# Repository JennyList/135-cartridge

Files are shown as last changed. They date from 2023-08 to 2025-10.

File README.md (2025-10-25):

# A Re-usable 35mm Film Cartridge
A 3D-printable re-usable film cartridge for 135 cameras.

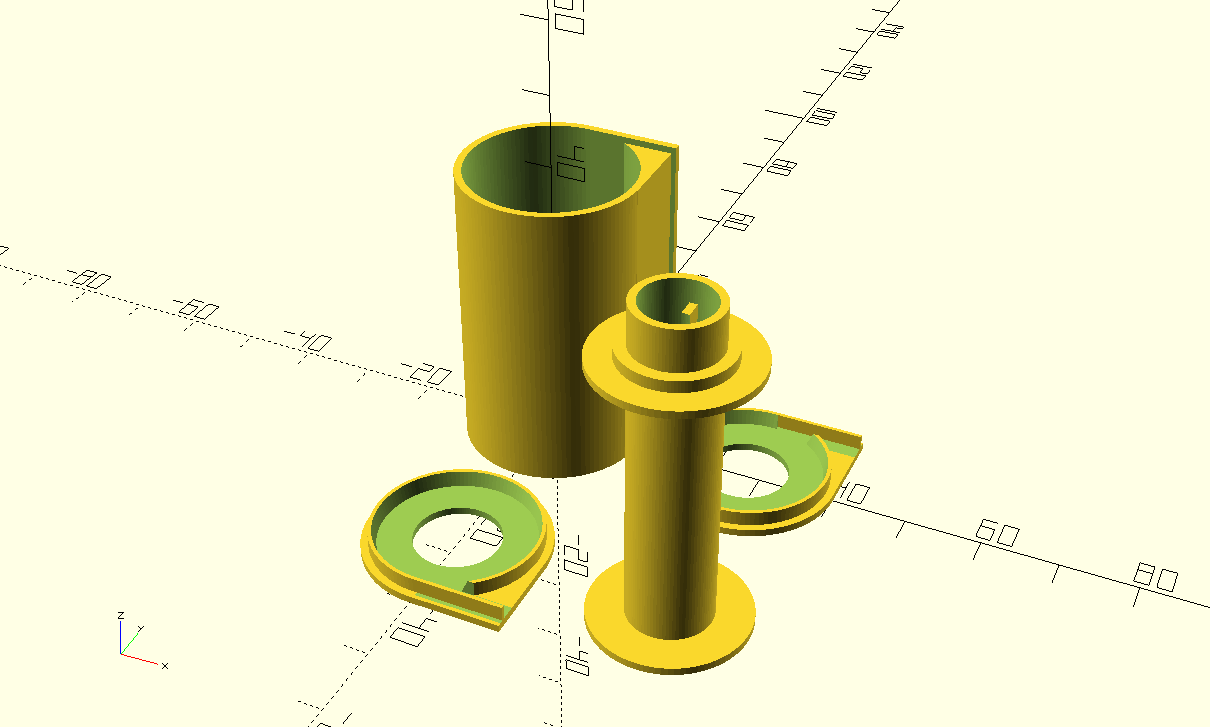
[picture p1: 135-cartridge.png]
A render of the STL for the cartridge


The cartridge, spool, and lids should be printed, then a set of two felt light seals should be glued along the opposite sides of the cartridge film opening. I used the soft side of a piece of black velcro, but a strip of black felt can also be used. Use a knife blade to keep the two felt pieces from sticking to each other. Once the glue has set, the felt can be trimmed at each end.

Once you've attached the felt, glue one end piece in place. Attach the film strip to the reel with a piece of tape, slide it into the cartridge with the film between the pieces of felt. Then place the other end piece on the cartridge and secure it with a piece of masking tape. You can then wind the film into the cartridge.

Take care for light leaks, suggest loading in a darkroom and avoiding strong light when loading your camera.

## Licence

This model is licensed under the [Creative Commons Attribution Share Alike 4.0 International licence](license.md).



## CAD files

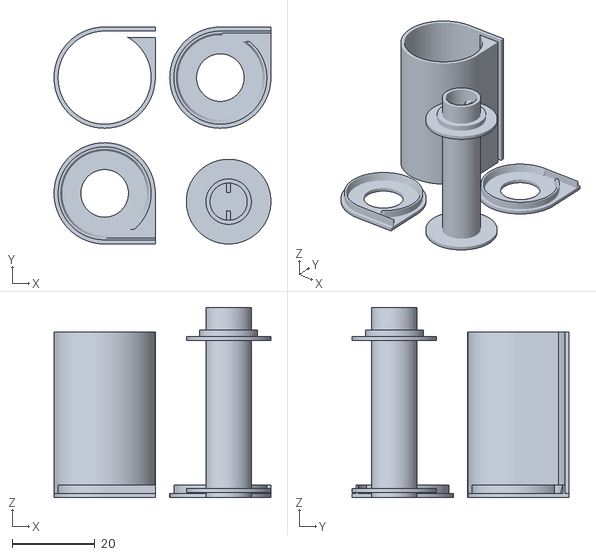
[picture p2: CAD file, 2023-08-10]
135-cartridge.stl
52.5 x 52.5 x 46.0

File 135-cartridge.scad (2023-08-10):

/*
A re-usable 135 film cartridge
Jenny List 2023
CC-BY-SA 4.0

*/
module Reel35(){
    difference(){
        union(){
            cylinder(46,5.5,5.5,$fn=90,true); //shaft
            translate([0,0,16.75]) cylinder(1.5,7,7,$fn=120,true); //spacer
            translate([0,0,-21.25]) cylinder(1,10.25,10.25,$fn=90,true); //bottom flange
            translate([0,0,15.5]) cylinder(1,10.25,10.25,$fn=90,true);//top flange
        } 
        translate([0,0,-15.5])cylinder(15,4.5,4.5,$fn=90,true); //cut out bottom 
        translate([0,0,15.5])cylinder(15,4.5,4.5,$fn=90,true); //cut out top
    }
    difference(){ //tabs for film winder to engage
        cube([1,10,40],true); 
        cylinder(40,2.25,2.25,$fn=90,true);
    }
}

module Lid35(){
    difference(){
        union(){
            cylinder(1,12.25,12.25,$fn=120,true); //flat lid
            translate([11.75,5.75,0])cube([1,13,1],true); //tangent
            translate([6,11.75,0])cube([12,1,1],true); //tangent.
            translate([5.5,5,0]) cube([13,13,1],true); //Cube to fill in the hole
            translate([0,0,1.5]) cylinder(2,11.25,11.25,$fn=120,true);// protrusion
           
        }
        translate([0,0,1.5]) cylinder(2,10.25,10.75,$fn=120,true); //carve out the middle.
        translate([7,10.25,1.5])cube([13,3,2],true); //tangent .
        cylinder(5,5.75,5.75,$fn=120,true); //hole
    }
    translate([0,10.75,0.5]) cube([12.25,0.5,2]);//straight bit of light seal on output
}

module Cartridge35(){
    difference(){
        union(){
            difference(){
                union(){
                    cylinder(40,12.25,12.25,$fn=120,true); //main cylinder
                    translate([11.75,5.75,0])cube([1,13,40],true); //tangent side
                    translate([6,11.75,0])cube([12,1,40],true); //tangent top
                    translate([5.5,5,0]) cube([13,13,40],true); //Cube to fill in the hole
                }
                cylinder(40,11.25,11.25,$fn=120,true);  //Carve out space for film
            }
        }
        translate([8,10.5,0])cube([16,1.5,40],true); //film guide

    }
}

translate([0,0,20]) Cartridge35();
translate([28,0,0.5]) Lid35();
mirror ([0,1,0]) translate([0,28,0.5]) Lid35();
translate([30,-30,23]) Reel35();
